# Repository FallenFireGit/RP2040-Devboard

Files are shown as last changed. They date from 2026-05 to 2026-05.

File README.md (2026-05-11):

# RP2040 Board

## NOTE TO REVIEWER

I didn’t end up recording a timelapse or keeping super consistent journal entries while working on this. Most of the project was done in longer sessions where I was focused on getting things working rather than documenting everything as I went (documenting is boring, and I got lazy). I realize now that I should’ve tracked progress better, but I’ve tried to reconstruct the main steps and decisions afterward as accurately as possible (In the 12-hour journal entry). In the future, I will remember to document more of my work as I go because I've now learned the importance of documenting. Also, this was my first project ever where I had to document, so now I understand how much I have documented moving forward. 

---

A custom-designed RP2040 development board built for expanded storage, improved power delivery, and practical usability in embedded and DIY CNC applications.

## Overview

This project is a fully custom PCB based on the RP2040 microcontroller, designed as an upgraded alternative to standard dev boards like the Raspberry Pi Pico.

The goal was to create a board that is:

* More powerful
* Easier to use during development
* Capable of handling real-world applications (data logging, robotics, etc.)

---

## Key Features

### Storage

* 8MB Flash (upgraded from 2MB)
* MicroSD Card Slot

  * Supports data logging and large file storage
  * Can be used for applications like G-code handling

---

### Interface & Controls

* Boot Button – Easy entry into bootloader mode
* Reset Button – Quick system reset during development
* Status LED (Bi-color)

  * Indicates power / charging state
* Master Power Switch

  * Fully cuts power to the board

---

### Power System

* LiPo Battery Support

  * Onboard charging circuit
* ~600mA Current Capacity

  * Supports more demanding peripherals
* 3.3V Enable Control (3V3_EN)

  * Allows software-controlled power management
* Optimized Power Traces

  * Wider 3.3V and GND lines for:

    * Reduced resistance
    * Lower heat
    * Improved stability

---

## Design Decisions

* Switched to a higher current voltage regulator for better performance
* Removed unnecessary components after redesign
* Standardized passive components to 0603:

  * Easier assembly
  * Cheaper sourcing
  * Better repairability

---

## PCB Design

* 4-Layer PCB

  * Dedicated ground plane for cleaner routing
  * Improved signal integrity and stability
* Double-sided component placement

  * Maximizes space efficiency

---

## Images





---

## Tools Used

* PCB Design: KiCad (or replace with your tool)
* Microcontroller: RP2040

---

## Status

* Schematic Complete
* PCB Layout Complete
* Manufacturing / Testing (Next Step)

---

## Goals

* Create a more capable RP2040 board than standard dev boards
* Support battery-powered applications
* Enable expandability through external storage

---

## Acknowledgments

* Inspired by the Raspberry Pi Pico
* Built as part of Hack Club Stasis

## BOM

Capacitors
* 0.1uF capacitors 402 – 10
* 1uF capacitors 402 – 2
* 10uF capacitors 805 – 5
* 22pF capacitors 402 – 2
* 0.5uF capacitor 402 – 1
* 100nF capacitor 402 – 1

Resistors
* 5.1k resistors 603 – 2
* 27.4 resistors 603 – 2 
* 100k resistors 603 – 2
* 1k resistors 603 – 3
* 10k resistors 603 – 2
* 47k resistors 603 – 3
* 200k resistor 603 – 1
* 2k resistor 603 – 1

Total Price of Passive Components ~ $1.90 (Depends on who you buy it from)

Diodes & Clock ~ $1.16
* SS14 diodes – 3 ~ $0.50 each
* SB0603W diode – 1 ~ $0.40 
* * 12MHz crystal – 1 ~ 0.70

Connectors / I/O ~ $4.75
* USB-C receptacle (HRO TYPE-C-31-M-12) – 1
* 1x20 pin headers (2.54mm) – 2
* 1x3 pin header (2.54mm) – 1
* 1x2 pin JST connector (PH series) – 1
* MicroSD card slot – 1

Switches ~ $1.20
* Push buttons (SPST) – 2
* Slider switch – 1

ICs / Chips 
* RP2040 – 1 $0.92
* MCP73831-2-OT (battery charger) – 1 $0.76
* W25Q64JVZPIQ (flash memory) – 1 $1.44
* AP2112K-3.3 (voltage regulator) – 1 $0.57

| Component | Quantity | Price (Est.) |
| :--- | :---: | :--- |
| **Passives** (Capacitors & Resistors) | 38 | $1.90 |
| **Diodes** (SS14, SB0603W) | 4 | $0.90 |
| **Clock** (12MHz Crystal) | 1 | $0.70 |
| **Connectors / I/O** (USB-C, Headers, JST, MicroSD) | 6 | $4.75 |
| **Switches** (Push buttons, Slider) | 3 | $1.20 |
| **RP2040** (Microcontroller) | 1 | $0.92 |
| **MCP73831-2-OT** (Battery Charger) | 1 | $0.76 |
| **W25Q64JVZPIQ** (Flash Memory) | 1 | $1.44 |
| **AP2112K-3.3** (Voltage Regulator) | 1 | $0.57 |
| **TOTAL** | **56** | **$13.14** |

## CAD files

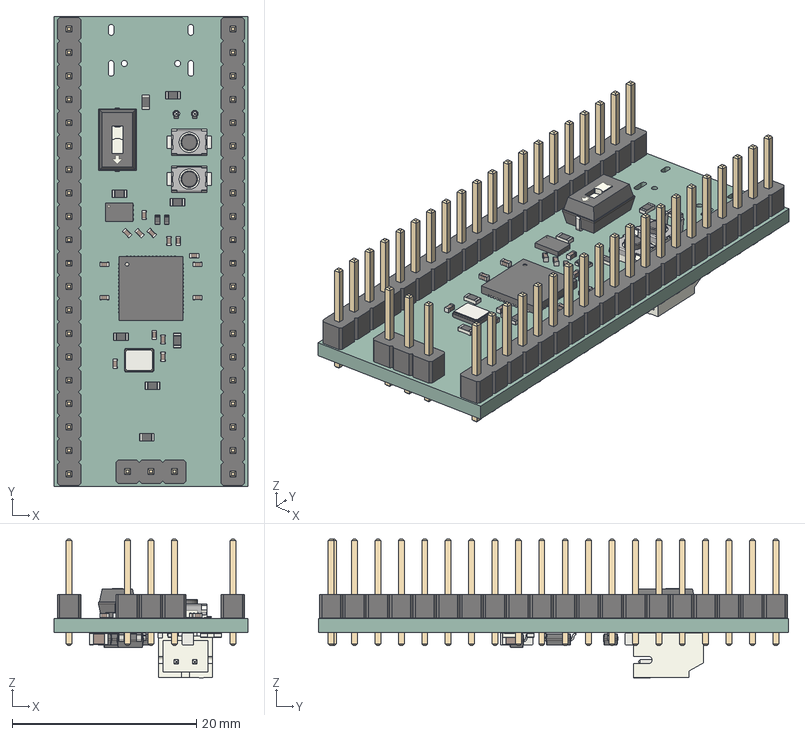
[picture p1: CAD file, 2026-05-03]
RP2040_CNC_Controller.step
21.0 x 51.0 x 15.1 mm
SW_DIP_SPSTx01_Slide_6.7x4.1mm_W6.73mm_P2.54mm_LowProfile_JPin
SW_Push_SPST_NO_Alps_SKRK x 2
Winbond_USON-8-1EP_3x2mm_P0.5mm_EP0.2x1.6mm
PinHeader_1x20_P2.54mm_Vertical x 2
Crystal_SMD_3225-4Pin_3.2x2.5mm
C_0402_1005Metric x 16
R_0603_1608Metric x 14
PinHeader_1x03_P2.54mm_Vertical
R_0402_1005Metric x 2
QFN-56-1EP_7x7mm_P0.4mm_EP3.2x3.2mm
D_SOD-123 x 3
SOT-23-5 x 2
C_0805_2012Metric x 5
JST_PH_S2B-PH-K_1x02_P2.00mm_Horizontal
RP2040_CNC_Controller_PCB

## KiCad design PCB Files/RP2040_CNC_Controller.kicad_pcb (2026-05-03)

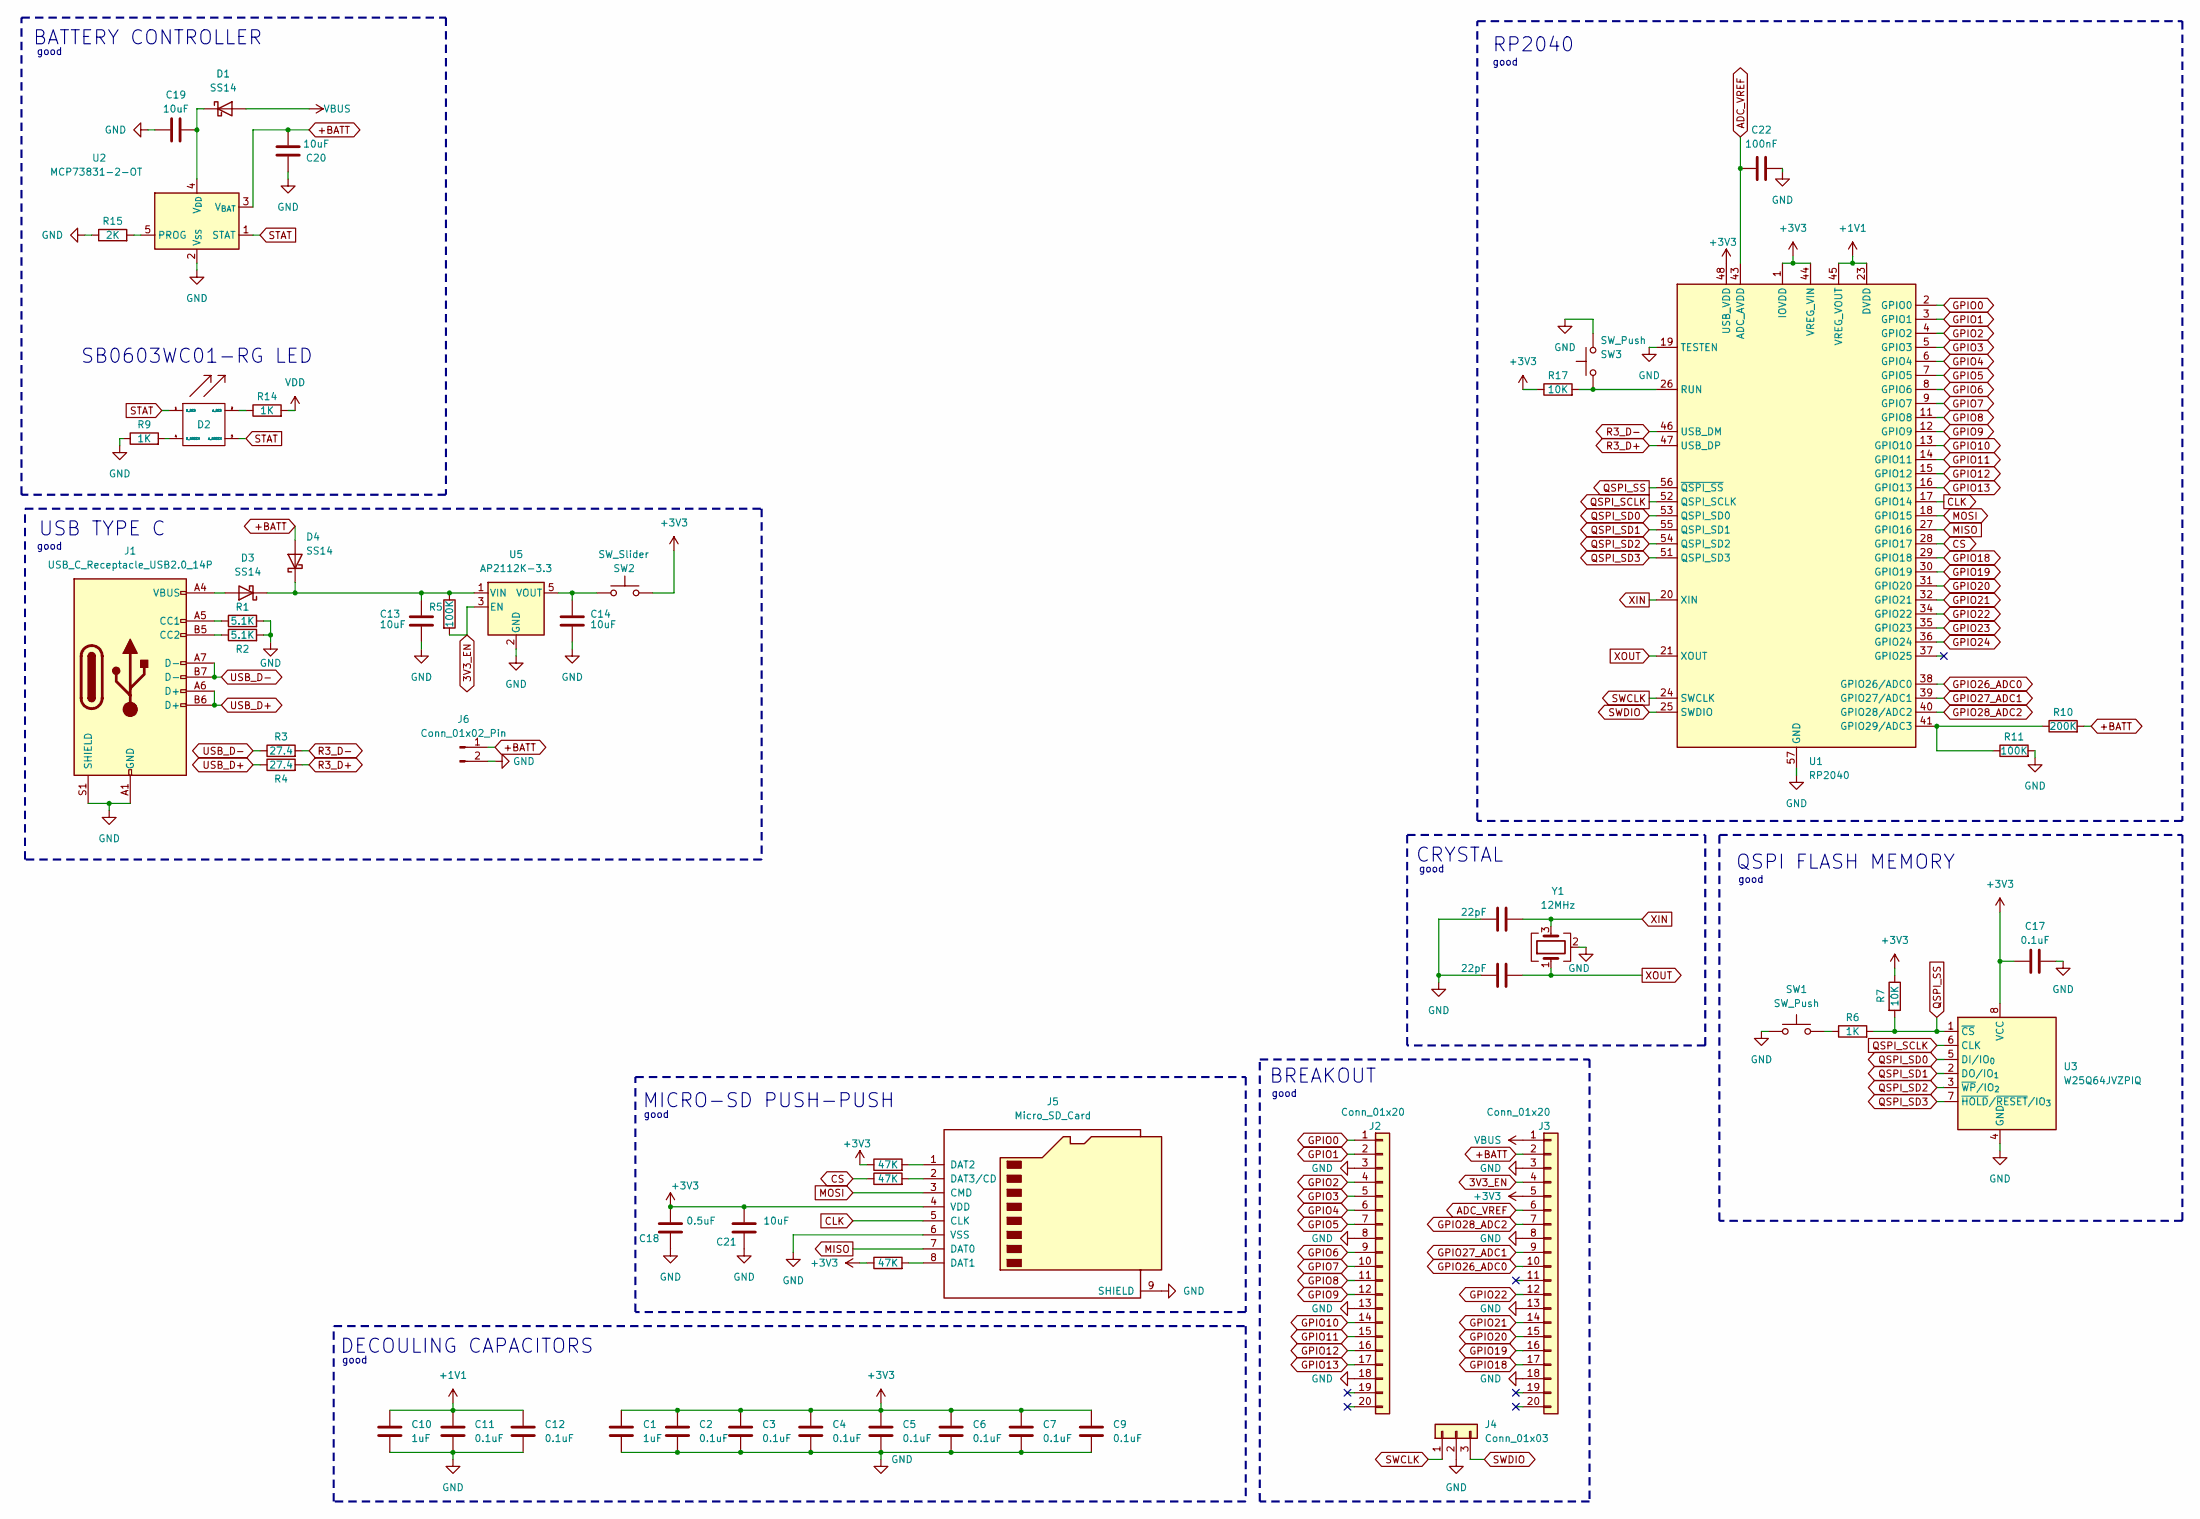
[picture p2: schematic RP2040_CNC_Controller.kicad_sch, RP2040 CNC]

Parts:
C1, C10: 1uF; C_0402_1005Metric
C2, C3, C4, C5, C6, C7, C9, C11, C12, C17: 0.1uF; C_0402_1005Metric
C13, C14, C19, C20, C21: 10uF; C_0805_2012Metric
C15, C16: 22pF; C_0402_1005Metric
C18: 0.5uF; C_0402_1005Metric
C22: 100nF; C_0402_1005Metric
D1, D3, D4: SS14; D_SOD-123
D2: SB0603WC01RG
J1: USB_C_Receptacle_USB2.0_14P; USB_C_Receptacle_HRO_TYPE-C-31-M-12
J2, J3: Conn_01x20; PinHeader_1x20_P2.54mm_Vertical
J4: Conn_01x03; PinHeader_1x03_P2.54mm_Vertical
J5: Micro_SD_Card; Micro_SD
J6: Conn_01x02_Pin; JST_PH_S2B-PH-K_1x02_P2.00mm_Horizontal
R1, R2: 5.1K; R_0603_1608Metric
R3, R4: 27.4; R_0402_1005Metric
R5, R11: 100K; R_0603_1608Metric
R6, R9, R14: 1K; R_0603_1608Metric
R7, R17: 10K; R_0603_1608Metric
R8, R12, R13: 47K; R_0603_1608Metric
R10: 200K; R_0603_1608Metric
R15: 2K; R_0603_1608Metric
SW1, SW3: SW_Push; SW_Push_SPST_NO_Alps_SKRK
SW2: SW_Slider; SW_DIP_SPSTx01_Slide_6.7x4.1mm_W6.73mm_P2.54mm_LowProfile_J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
U1: RP2040; QFN-56-1EP_7x7mm_P0.4mm_EP3.2x3.2mm
U2: MCP73831-2-OT; SOT-23-5
U3: W25Q64JVZPIQ; Winbond_USON-8-1EP_3x2mm_P0.5mm_EP0.2x1.6mm
U5: AP2112K-3.3; SOT-23-5
Y1: 12MHz; Crystal_SMD_3225-4Pin_3.2x2.5mm

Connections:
3V3_EN: J3.4, R5.2, U5.3 (EN)
+1V1: C10.1, C11.1, C12.1, U1.23 (DVDD), U1.45 (VREG_VOUT), U1.50 (DVDD)
+3V3: C1.1, C2.1, C3.1, C4.1, C5.1, C6.1, C7.1, C9.1, C17.1, C18.2, C21.2, J3.5, J5.4 (VDD), R7.1, R12.1, R13.1, R17.1, SW2.2, U1.1 (IOVDD), U1.10 (IOVDD), U1.22 (IOVDD), U1.33 (IOVDD), U1.42 (IOVDD), U1.44 (VREG_VIN), U1.48 (USB_VDD), U1.49 (IOVDD), U3.8 (VCC); also elsewhere on the board
+BATT: C20.1, D4.2 (A), J3.2, J6.1, R10.2, U2.3 (V_{BAT})
ADC_VREF: C22.1, J3.6, U1.43 (ADC_AVDD)
CLK: J5.5 (CLK), U1.17 (GPIO14)
CS: R8.1, U1.28 (GPIO17)
GND: C1.2, C2.2, C3.2, C4.2, C5.2, C6.2, C7.2, C9.2, C10.2, C11.2, C12.2, C13.2, C14.2, C15.1, C16.1, C17.2, C18.1, C19.1, C20.2, C21.1, C22.2, J1.A1 (GND), J1.A12 (GND), J1.B1 (GND), J1.B12 (GND), J1.S1 (SHIELD), J2.3, J2.8, J2.13, J2.18, J3.3, J3.8, J3.13, J3.18, J4.2, J5.6 (VSS), J5.9 (SHIELD), J6.2, R1.2, R2.2, R9.1, R11.2, R15.1, SW1.1, SW3.2, U1.19 (TESTEN), U1.57 (GND), U2.2 (V_{SS}), U3.4 (GND), U5.2 (GND), Y1.2 (G), Y1.4 (G); also elsewhere on the board
GPIO0: J2.1, U1.2 (GPIO0)
GPIO1: J2.2, U1.3 (GPIO1)
GPIO2: J2.4, U1.4 (GPIO2)
GPIO3: J2.5, U1.5 (GPIO3)
GPIO4: J2.6, U1.6 (GPIO4)
GPIO5: J2.7, U1.7 (GPIO5)
GPIO6: J2.9, U1.8 (GPIO6)
GPIO7: J2.10, U1.9 (GPIO7)
GPIO8: J2.11, U1.11 (GPIO8)
GPIO9: J2.12, U1.12 (GPIO9)
GPIO10: J2.14, U1.13 (GPIO10)
GPIO11: J2.15, U1.14 (GPIO11)
GPIO12: J2.16, U1.15 (GPIO12)
GPIO13: J2.17, U1.16 (GPIO13)
GPIO18: J3.17, U1.29 (GPIO18)
GPIO19: J3.16, U1.30 (GPIO19)
GPIO20: J3.15, U1.31 (GPIO20)
GPIO21: J3.14, U1.32 (GPIO21)
GPIO22: J3.12, U1.34 (GPIO22)
GPIO23: U1.35 (GPIO23)
GPIO24: U1.36 (GPIO24)
GPIO26_ADC0: J3.10, U1.38 (GPIO26/ADC0)
GPIO27_ADC1: J3.9, U1.39 (GPIO27/ADC1)
GPIO28_ADC2: J3.7, U1.40 (GPIO28/ADC2)
MISO: J5.7 (DAT0), U1.27 (GPIO16)
MOSI: J5.3 (CMD), U1.18 (GPIO15)
unnamed: C19.2, D1.1 (K), U2.4 (V_{DD})
unnamed: D2.2 (A_RED), R14.1
unnamed: D2.4 (K_GREEN), R9.2
unnamed: D3.2 (A), J1.A4 (VBUS), J1.A9 (VBUS), J1.B4 (VBUS), J1.B9 (VBUS)
unnamed: C13.1, D3.1 (K), D4.1 (K), R5.1, U5.1 (VIN)
unnamed: J1.A5 (CC1), R1.1
unnamed: J1.B5 (CC2), R2.1
unnamed: J5.8 (DAT1), R13.2
unnamed: J5.1 (DAT2), R12.2
unnamed: J5.2 (DAT3/CD), R8.2
unnamed 44: R6.1, SW1.2; also elsewhere on the board
unnamed: R10.1, R11.1, U1.41 (GPIO29/ADC3)
unnamed 46: R17.2, SW3.1, U1.26 (RUN); also elsewhere on the board
unnamed: R15.2, U2.5 (PROG)
unnamed 48: C14.1, SW2.1, U5.5 (VOUT); also elsewhere on the board
QSPI_SCLK: U1.52 (QSPI_SCLK), U3.6 (CLK)
QSPI_SD0: U1.53 (QSPI_SD0), U3.5 (DI/IO_{0})
QSPI_SD1: U1.55 (QSPI_SD1), U3.2 (DO/IO_{1})
QSPI_SD2: U1.54 (QSPI_SD2), U3.3 (~WP/IO_{2})
QSPI_SD3: U1.51 (QSPI_SD3), U3.7 (~HOLD/~RESET/IO_{3})
QSPI_SS: R6.2, R7.2, U1.56 (~QSPI_SS), U3.1 (~CS)
R3_D+: R4.2, U1.47 (USB_DP)
R3_D-: R3.2, U1.46 (USB_DM)
STAT: D2.1 (K_RED), D2.3 (A_GREEN), U2.1 (STAT)
SWCLK: J4.1, U1.24 (SWCLK)
SWDIO: J4.3, U1.25 (SWDIO)
USB_D+: J1.A6 (D+), J1.B6 (D+), R4.1
USB_D-: J1.A7 (D-), J1.B7 (D-), R3.1
VBUS: D1.2 (A), J3.1
VDD: R14.2
XIN: C15.2, U1.20 (XIN), Y1.3
XOUT: C16.2, U1.21 (XOUT), Y1.1

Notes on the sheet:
good
DECOULING CAPACITORS
MICRO-SD PUSH-PUSH
BREAKOUT
BATTERY CONTROLLER
CRYSTAL
SB0603WC01-RG LED
QSPI FLASH MEMORY
USB TYPE C
RP2040

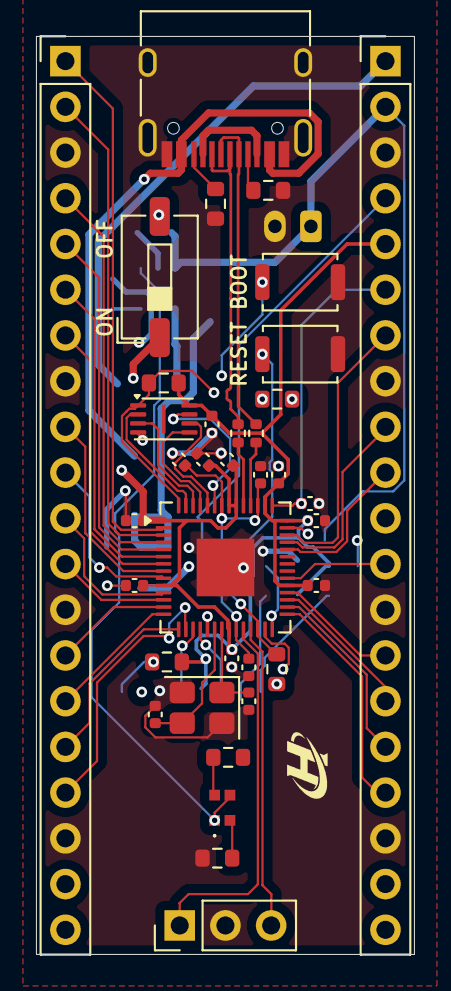
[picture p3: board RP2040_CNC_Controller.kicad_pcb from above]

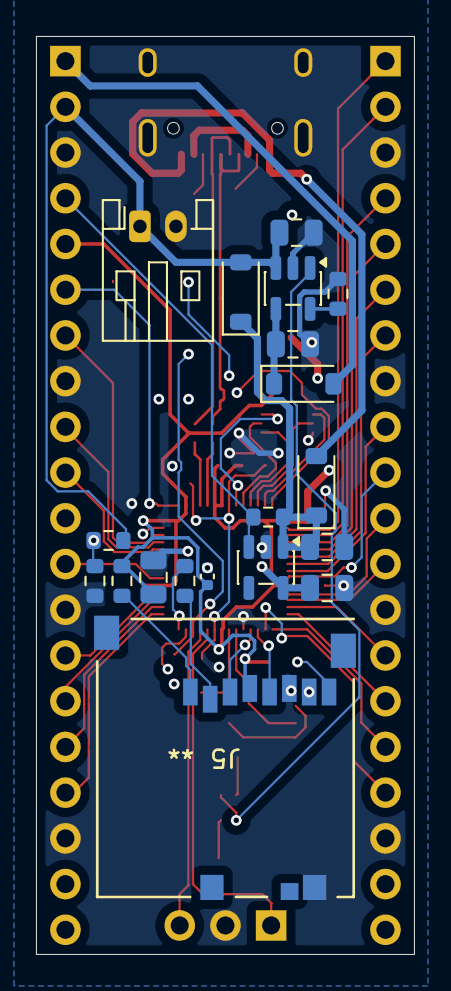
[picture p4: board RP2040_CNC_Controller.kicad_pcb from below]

Board: 4 copper layers, 21.0 x 51.0 mm, 55 parts (19 on the bottom side), 63 nets.

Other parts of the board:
BOOT: SW_Push; SW_Push_SPST_NO_Alps_SKRK
ON: SW_Slider; SW_DIP_SPSTx01_Slide_6.7x4.1mm_W6.73mm_P2.54mm_LowProfile_J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
RESET: SW_Push; SW_Push_SPST_NO_Alps_SKRK

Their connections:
+3V3: ON.2; also elsewhere on the board
GND: BOOT.1, RESET.2; also elsewhere on the board
unnamed 44: BOOT.2; also elsewhere on the board
unnamed 46: RESET.1; also elsewhere on the board
unnamed 48: ON.1; also elsewhere on the board

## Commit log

2026-05-03 Rename RP2040_CNC_Controller.kicad_pcb to PCB Files/RP2040_CNC_Controller.kicad_pcb
    [RP2040_CNC_Controller.kicad_pcb]
2026-05-03 Rename RP2040_CNC_Controller.kicad_pro to PCB Files/RP2040CNC_Controller.kicad_pro
2026-05-03 Rename RP2040_CNC_Controller.kicad_sch to PCB Files/RP2040_CNC_Controller.kicad_sch
    [RP2040_CNC_Controller.kicad_sch]
2026-05-03 Rename RP2040_Manufactuer.zip to Gerber Files/RP2040_Manufactuer.zip
